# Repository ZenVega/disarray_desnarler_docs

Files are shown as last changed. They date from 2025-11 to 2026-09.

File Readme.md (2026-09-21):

# Macropad Collection

Open-hardware build documentation — KiCad projects, gerbers, bills of materials, laser-cut cases and artwork — for two custom macropads.

## The macropads

### [DisArray Desnarler](./disarray_desnarler/) &nbsp;→&nbsp; `disarray_desnarler/`

The original Schreibtischordnungsdienst macropad: a XIAO-RP2040 pad with hot-swap switches, an analog fader, and an optional rotary encoder, flashed with QMK. Includes the full build guide, laser-cut case, 3D-printed fader knob, sticker artwork, and the configuration instructions.

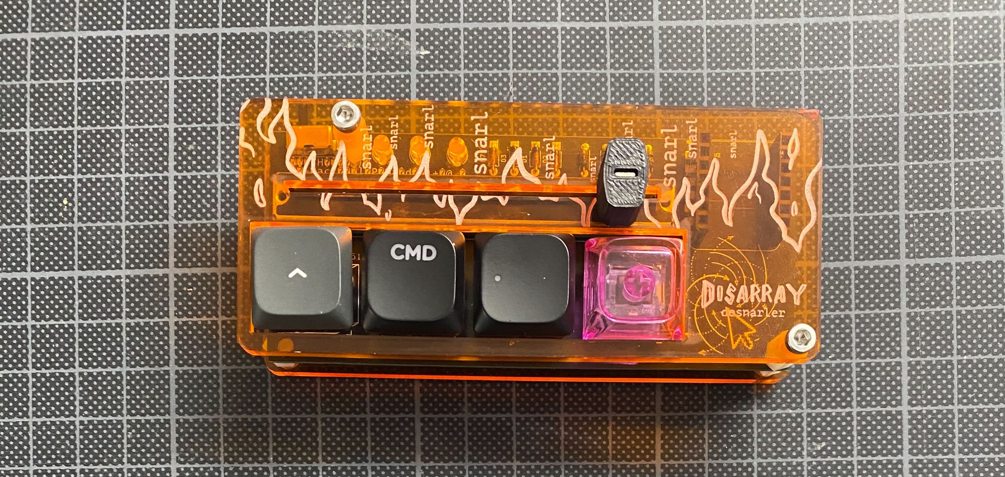
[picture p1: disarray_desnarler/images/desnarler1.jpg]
DisArray Desnarler


For a project overview, see [the Hackaday project page](https://hackaday.io/project/204536-disarray-desnarler).

### [macro_GOAT](./macro_GOAT/) &nbsp;→&nbsp; `macro_GOAT/`

An RP2040-Zero macropad with a 16-LED WS2812B array, hot-swap switches, and up to 4 optional EC11 rotary encoders. Includes the KiCad project, gerbers, SMD stencil, and the board artwork.

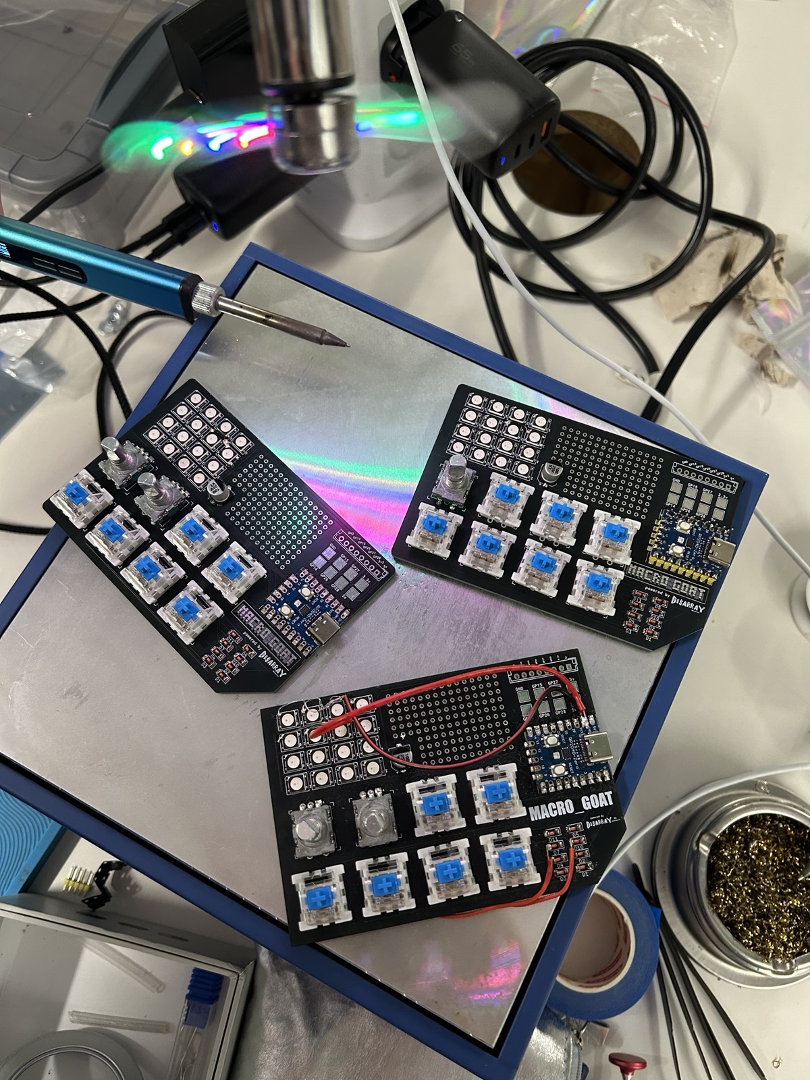
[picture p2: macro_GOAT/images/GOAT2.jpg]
macro_GOAT


Both pads share the QMK firmware repository [ZenVega/qmk_disarray_desnarler](https://github.com/ZenVega/qmk_disarray_desnarler), which now holds keymaps for the Desnarler and the macro_GOAT.

## Repository layout

```
disarray_desnarler/      first macropad (build docs, PCB versions, case, configuration instructions)
macro_GOAT/              second macropad (PCB, gerbers, stencil, artwork)
instructions/            shared QMK flashing guide used by both boards
symbols_and_footprints/  shared KiCad symbol & footprint libraries used by both boards
```

> **KiCad note:** each project's `fp-lib-table` / `sym-lib-table` still contains machine-specific
> paths from the original authoring environment. The shared libraries now live at the repo root in
> [`symbols_and_footprints/`](./symbols_and_footprints/); re-point the library tables there when
> opening a project in KiCad.

## License

See [LICENSE](./LICENSE).

&mdash; _your Schreibtischordnungsdienst_

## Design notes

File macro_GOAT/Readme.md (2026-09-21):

# macro_GOAT

A custom macropad built around an RP2040-Zero with a 16-LED WS2812B array, hot-swap
switches, and up to 4 optional EC11 rotary encoder.

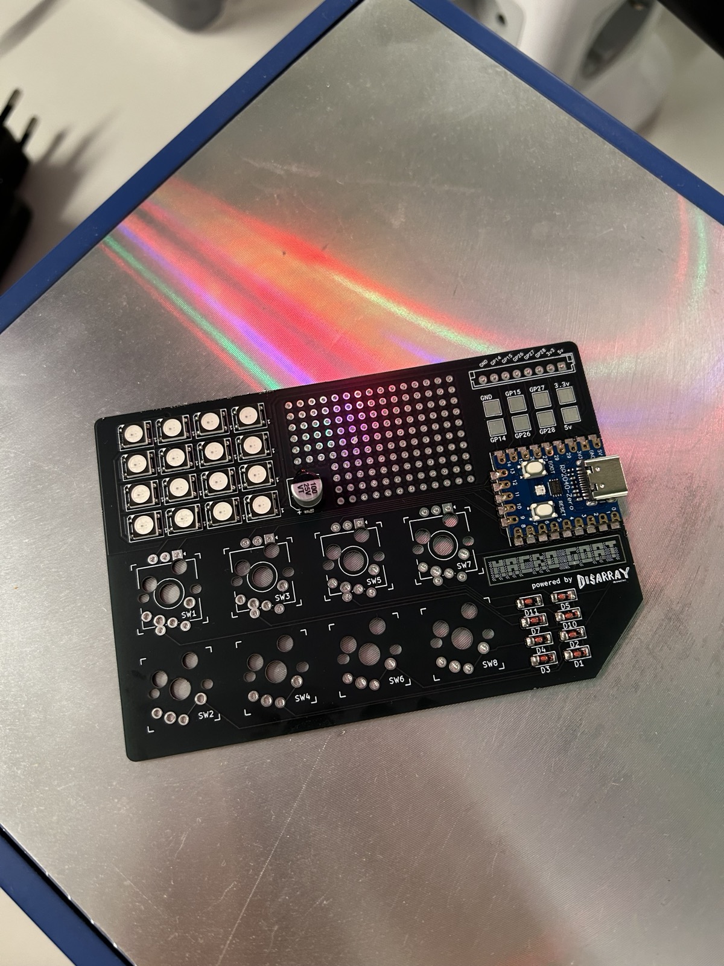
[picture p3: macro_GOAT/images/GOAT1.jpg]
macro_GOAT

macro_GOAT

🎬 [Watch the demo video](./images/GOAT_demo.mp4)

## What's in this folder

```
pcb/v1.0/        KiCad project, gerbers, SMD stencil and BOM.md
  gerbers/         fabrication gerbers (+ stencil/ for the SMD stencil)
  chaos_array.*    KiCad schematic / board / project files
  smd_stencil.svg  stencil artwork
  BOM.md           bill of materials
artwork/         board graphics — the macro_GOAT logo studies and silkscreen text
images/          build photos and demo video
```

> The KiCad project files are still named `chaos_array.*` (the board's original name).
> The shared KiCad symbol and footprint libraries live at the repository root in
> [`../symbols_and_footprints/`](../symbols_and_footprints/); the project's
> `fp-lib-table` / `sym-lib-table` may need re-pointing there when opening in KiCad.

## Bill of materials

See [`pcb/v1.0/BOM.md`](./pcb/v1.0/BOM.md).

## Firmware

The macro_GOAT keymap lives in the shared QMK repository
[ZenVega/qmk_disarray_desnarler](https://github.com/ZenVega/qmk_disarray_desnarler)
(alongside the DisArray Desnarler keymap). Flash it with QMK using the shared
[flashing guide](../instructions/How_to_flash.md).

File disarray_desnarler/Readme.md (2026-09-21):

# DisArray Desnarler

Congrats on getting your first own DisArray Desnarler. We are happy to have you here and help you organise your desktop.

For a quick overview of the project, have a look at [the Hackaday project page](https://hackaday.io/project/204536-disarray-desnarler).

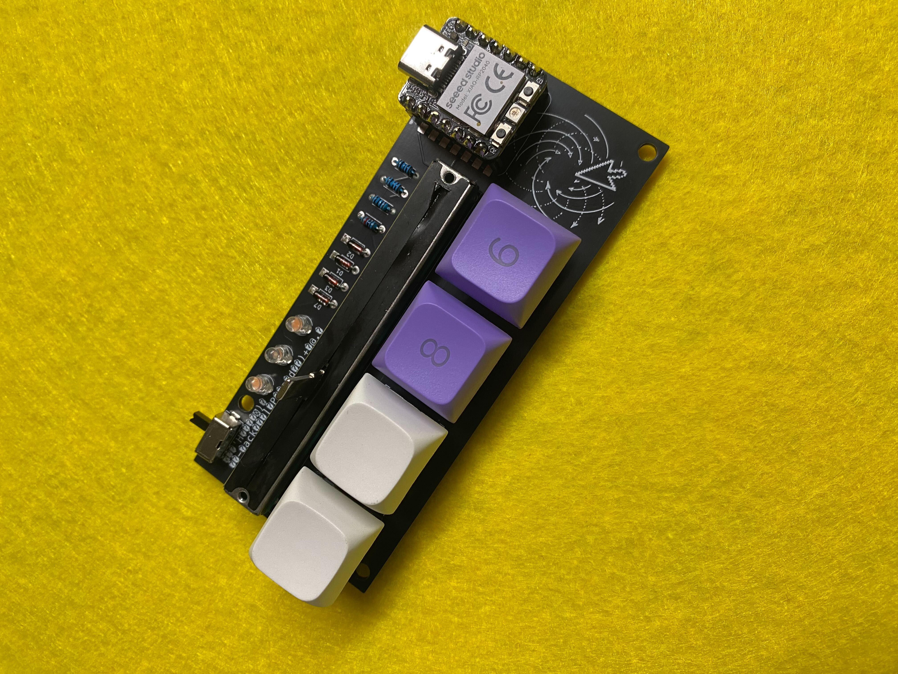
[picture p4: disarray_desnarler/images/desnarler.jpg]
DisArray Desnarler


&mdash; _your Schreibtischordnungsdienst_

## What's in this folder

```
pcb/v1.1/        current PCB — KiCad project, gerbers and BOM.md
pcb/v0.5/        earlier PCB revision (archived)
instructions/    configuration and Umlaut guides (flashing guide is shared, see ../instructions/)
case/            laser-cut case (current_version/ + old_version/)
build_guide/     assembly build diagram
3d_prints/       fader knob STL
logo/            logo and sticker artwork
images/          photos and diagrams
artwork/         PCB silkscreen / mask vector art
```

The shared KiCad symbol and footprint libraries live at the repository root in [`../symbols_and_footprints/`](../symbols_and_footprints/).

## Soldering instructions

The PCBs are sponsored by [PCBWay](https://www.pcbway.com/). Thanks for the support. Check out their services for high-quality PCBs and fast service.

All components should be soldered to the front of the board, with the exception of the optional hotswap sockets (d).

The alphabetical markers in this diagram show the recommended soldering order, based on the height of the components. Note that while "a" through "c" are next to each other in the diagram, the rest of the sequence is scattered. Be careful not to simply go clockwise.

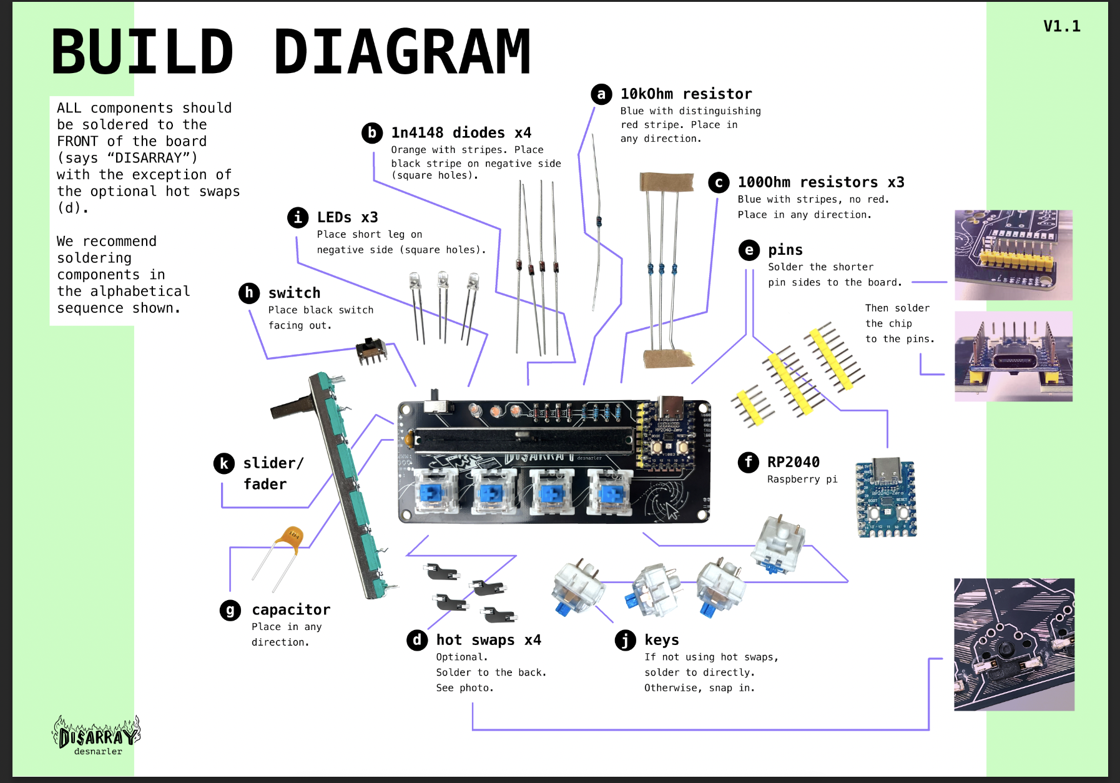
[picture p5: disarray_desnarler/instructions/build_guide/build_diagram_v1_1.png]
Soldering instructions


The full bill of materials is in [`pcb/v1.1/BOM.md`](./pcb/v1.1/BOM.md).

### Using the Desnarler as a Macropad

After you are done soldering, it is time to flash your Desnarler with some QMK firmware to make it ready for use. Let's start with a keymap we provide.

For this, please refer to the [How_to_flash](../instructions/How_to_flash.md) guide.

If you are interested in configuring the Desnarler yourself, see [How_to_configure](./instructions/How_to_configure.md).

If you are looking for an option to change the meaning of the keys a bit more easily check out the [Companion App](https://github.com/ZenVega/qmk_disarray_desnarler/blob/main/companion-app/README.md) (works with MacOS only).

### What you can also do

You can also use your Desnarler to play [Vimchaser!](https://github.com/uschi909/vimchaser)

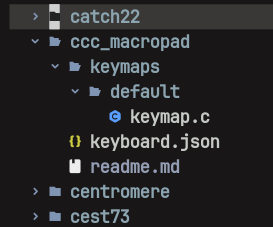
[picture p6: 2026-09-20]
disarray_desnarler/images/qmk_keyboard_files.png

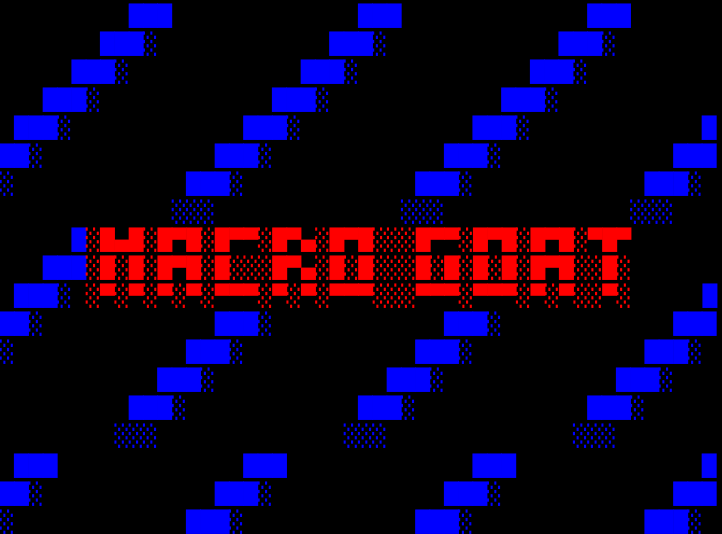
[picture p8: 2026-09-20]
macro_GOAT/artwork/ascii-art-text.png

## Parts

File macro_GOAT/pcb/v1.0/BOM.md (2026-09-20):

#Bill of Materials

| part | amount | link |
| --- | --- | --- |
| WS2812B RGB LED | 16 | https://de.aliexpress.com/item/4001345875756.html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 |
| LLIN4148 | 8 | https://de.aliexpress.com/item/1005006783983904.html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 |
| EC11 Rotary Encoder | optional | https://de.aliexpress.com/item/1005010636860645.html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 |

:

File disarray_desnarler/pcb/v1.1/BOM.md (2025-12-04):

| Reference | Qty | Value | Price / Amount | Datasheet 
| :--- | ---:| :--- | --- | :---
| D1, D2, D3,D7 |  4  | 1N4148WT | 1.09 / 100 | [Link](https://de.aliexpress.com/item/1005007807649334.html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) 
| D6, D8, D9 |  3  | LED | 2.19 / 100 | [Pink version](https://de.aliexpress.com/item/1005003320296052.html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)
| R1, R2, R3 |  3  | 100R | 1.65 / 100 | [Link] (https://de.aliexpress.com/item/32847096736.html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)
| R4 |  1  | 10k | 0.99 / 100 | [Link] (https://de.aliexpress.com/item/1005008175194639.html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)
| RV1 |  1  | Analogue_input_slider 10k | 2.55 / 5 | [Link] (https://de.aliexpress.com/item/1005006306313902.html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)
| SW1,SW2,SW4,SW5 | 4 | SW_Push | | ~ 
| SW1,SW2,SW4,SW5 | 4 | kaihl_hot_swaps | 2.99 / 30 | [Link] (https://de.aliexpress.com/item/1005009443356291.html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)
SW3           |  1  | OS/Left_Right-hand_Switch      | 1.69 / 50      | [Link](https://de.aliexpress.com/item/1005006123805028.html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,scm-url:1007.40050.354490.0,pvid:71a908dc-51c8-4ef3-aafd-85a7bed5551c,tpp_buckets:668%232846%238107%231934&pdp_ext_f=%7B%22order%22%3A%2271%22%2C%22eval%22%3A%221%22%2C%22sceneId%22%3A%2230050%22%2C%22fromPage%22%3A%22recommend%22%7D&pdp_npi=6%40dis%21EUR%214.97%211.69%21%21%2140.60%2113.80%21%40211b618e17595754708595171e8e66%2112000035859852610%21rec%21DE%216126981087%21XZ%211%210%21n_tag%3A-29919%3Bd%3A46f825b0%3Bm03_new_user%3A-29895&utparam-url=scene%3ApcDetailTopMoreOtherSeller%7Cquery_from%3A%7Cx_object_id%3A1005006123805028%7C_p_origin_prod%3A)         
| U1            |  1  | XIAO-RP2040-DIP              |                | ~

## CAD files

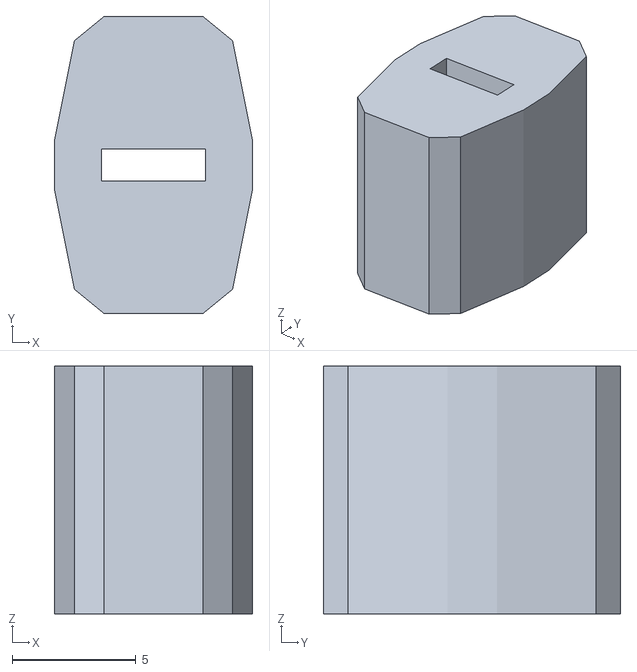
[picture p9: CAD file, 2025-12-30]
disarray_desnarler/3d_prints/Fader_knob-Body.stl
8.00 x 12.0 x 10.0

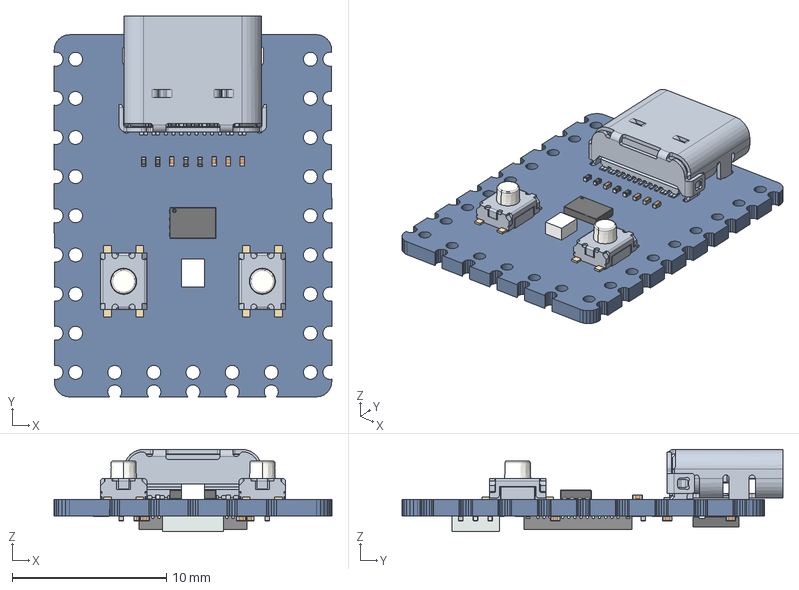
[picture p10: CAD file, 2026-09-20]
symbols_and_footprints/RP2040_Zero.stp
18.0 x 24.7 x 5.34 mm
BOARD
ANSCHL_X_FCSSE_1 x 9
K_X_F6RPER_1 x 9
EXTRUDED-32530
USER_LIBRARY-CHIP_CAP_MLCC_0201 x 19
EXTRUDED-36548
USER_LIBRARY-RP2040_QFN56_04
USER_LIBRARY-8MA3_1
USER_LIBRARY-8MA3_2
EXTRUDED-175432
EXTRUDED-175804 x 5
TS-1185EC-A-E-A-1 x 2
EXTRUDED-374538 x 10

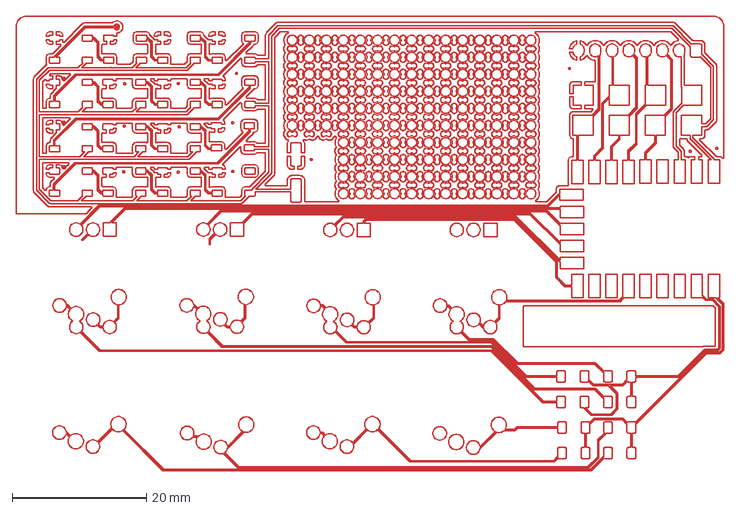
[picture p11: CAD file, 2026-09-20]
macro_GOAT/pcb/v1.0/gerbers/stencil/chaos_array-Front.dxf
105.4 x 67.7 mm

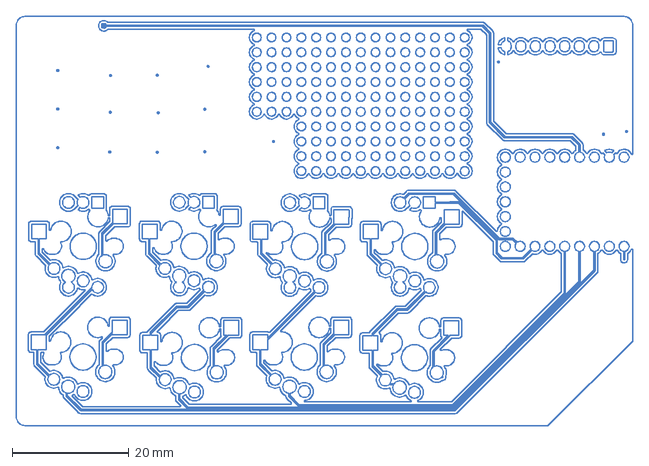
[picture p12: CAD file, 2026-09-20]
macro_GOAT/pcb/v1.0/gerbers/stencil/chaos_array-Back.dxf
105.4 x 70.0 mm

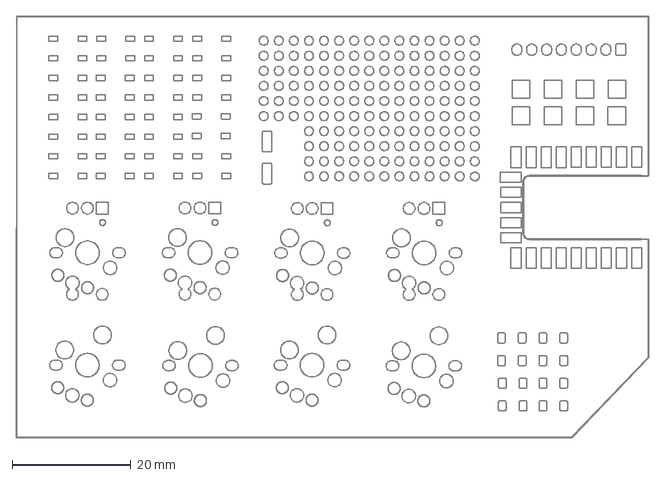
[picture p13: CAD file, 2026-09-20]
macro_GOAT/pcb/v1.0/gerbers/stencil/smd_stencil.dxf
106.5 x 71.0 mm

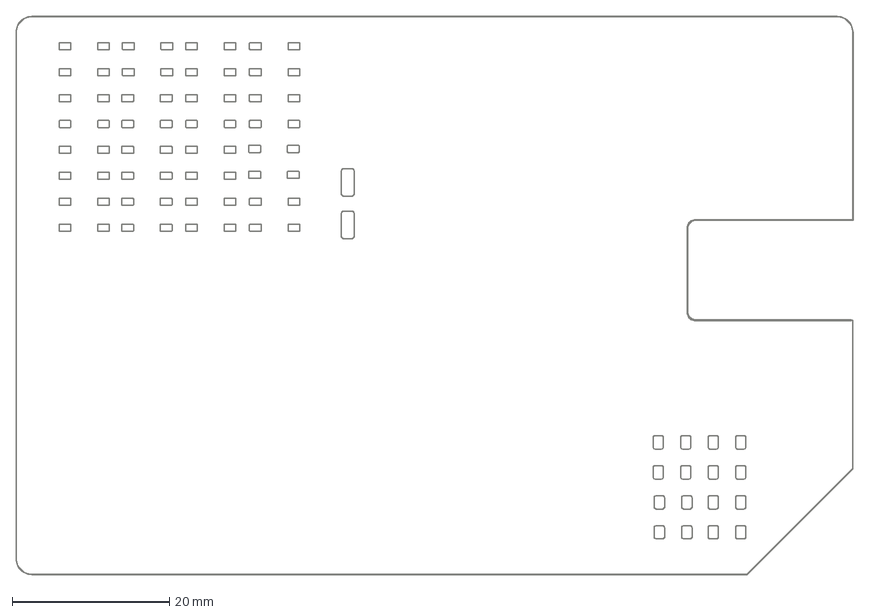
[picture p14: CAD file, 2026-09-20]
macro_GOAT/pcb/v1.0/gerbers/stencil/chaos_array-Edge_Cuts.dxf
106.5 x 71.0 mm

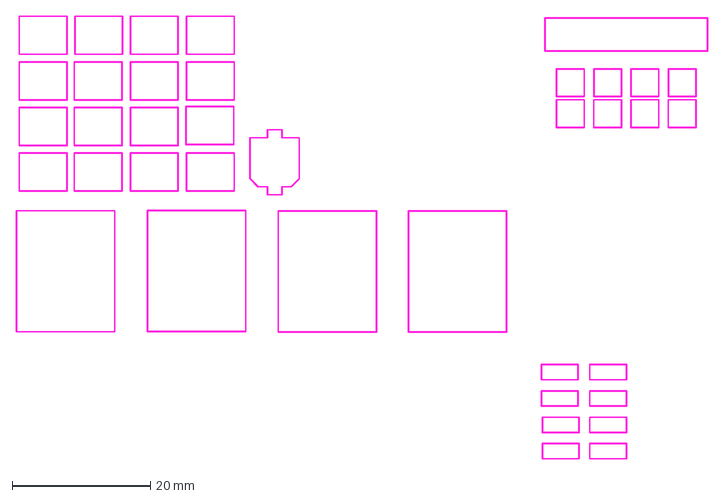
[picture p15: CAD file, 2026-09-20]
macro_GOAT/pcb/v1.0/gerbers/stencil/chaos_array-F_Courtyard.dxf
100.0 x 64.1 mm

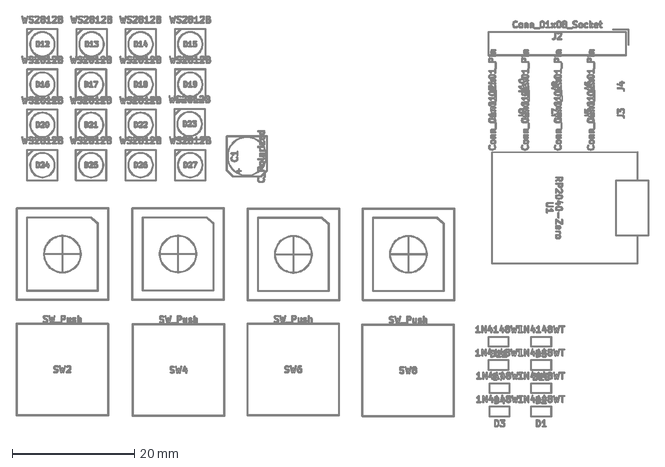
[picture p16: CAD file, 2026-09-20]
macro_GOAT/pcb/v1.0/gerbers/stencil/chaos_array-F_Fab.dxf
103.7 x 67.3 mm

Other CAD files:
macro_GOAT/pcb/v1.0/gerbers/stencil/chaos_array-B_Courtyard.dxf
macro_GOAT/pcb/v1.0/gerbers/stencil/chaos_array-Margin.dxf
macro_GOAT/pcb/v1.0/gerbers/stencil/chaos_array-B_Mask.dxf
macro_GOAT/pcb/v1.0/gerbers/stencil/chaos_array-B_Paste.dxf
macro_GOAT/pcb/v1.0/gerbers/stencil/chaos_array-B_Silkscreen.dxf
macro_GOAT/pcb/v1.0/gerbers/stencil/chaos_array-F_Mask.dxf
macro_GOAT/pcb/v1.0/gerbers/stencil/chaos_array-F_Paste.dxf
macro_GOAT/pcb/v1.0/gerbers/stencil/chaos_array-F_Silkscreen.dxf

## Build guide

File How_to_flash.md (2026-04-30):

### Great! you finished soldering!

### so let's go ahead and flash some firmware onto your Desnarler!

If you are in a workshop with us, we will help you and flash the first round with you, or you even got an already flashed microcontroller.

If you feel comfortable with the terminal and an IDE of your choice: This guide is for you.



# Prepare: Install QMK

This is just a quick recap. If you get stuck, check the official qmk documentation [here](https://docs.qmk.fm/newbs_getting_started)

In order to get QMK CLI installed on your system follow the first two steps from the [installation instructions] (https://docs.qmk.fm/newbs_getting_started)

Test if installation was successfull:

```bash
qmk --version
```

# Flash Desnarler

Clone this [repo](https://github.com/ZenVega/qmk_for_macropad/tree/main) containing the firmware and the macropad layout and keymap.

To install all missing dependencies run:

```bash
git submodule update --init --recursive

git submodule sync --recursive
git submodule update --init --recursive --force
```

## Chose Keymap

We provide a few different keymaps, that we think will be useful to you.
When you look around in the repo you just cloned, there is a directory "keyboards". Within this choose the directory corresponding to the keyboard you have - in your case it is a DesnarlerV1. Within this directory there are different keymaps to configure what your Desnarler does.

### default keymap

As the name says, this keymap should be used on a Linux OS.
There are two independent sets of layouts.

If the switch on the top left of the Desnarler is to the left:

- The 2 most right keys will navigate workspaces without dragging your current window.
- Pressing the left most key plus one of the right most keys will navigate through workspaces while dragging the current window along.
- Pressing the second key to the left will activate the 2 right keys to circle through all the open applications
- holding the 2 right most keys and pressing one of the other 2 will log you out or put your system to sleep

If the switch it to the right, the focus is on rearranging the windows within a workspace

- the 2 left most keys will move the currently active windows to the left or right half of the screen.
- having activated the left most key, the 2 keys on the right will maximize and minimize the current window
- holding the second key to the left will let you switch workspaces without dragging the current window
- holding the 2 right most keys and pressing one of the other 2 will log you out or put your system to sleep

More information on this map and an easy introduction into QMK you will find [here](./How_to_configure.md)

### German Umlaute ä, ö, ü

This keymap has the German Umlaute on the second set of layers (switch to the right), including the option to get the capital Umlaute. More thoughts on this map and a slightly deeper dive into QMK [here](./How_to_Umlaut.md)

## Compile

After you have chosen your preferred keymap, you are ready to compile.

Compilation will create a \*.bin that holds the firmware including your compilation ready to be flashed on the MCU

```bash
qmk compile -kb <keyboard> -km <keymap>
```

so a likely use will be

```bash
qmk compile -kb desnarler_v1 -km default
```

If no keyboard is defined, your keymap is 'default'. (which might not be defined in all cases)

### Flash

After compilation you are ready to flash qmk to your microcontroller (rp2040 in this case): plug it in and set it into bootloader mode.
This requires pressing the boot button while plugging it in. The device should show up as a flashable media in your files-explorer.
run:

```bash
qmk flash -kb <keyboard> -km <keymap>
```

so likely you will use

```bash
qmk flash -kb desnarler_v1 -km default
```

#### Troubleshooting Flashing

If your have done minor changes to your firmware, flashed and everything seemed fine, but the old firmware is still booting, download this [nuke file](https://datasheets.raspberrypi.com/soft/flash_nuke.uf2). Once downloaded, copy it onto your RP2040 while in bootloader mode. This will erase all traces of the former firmware. Then just flash again.

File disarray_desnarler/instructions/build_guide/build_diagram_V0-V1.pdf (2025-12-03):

V0-V1

# BUILD

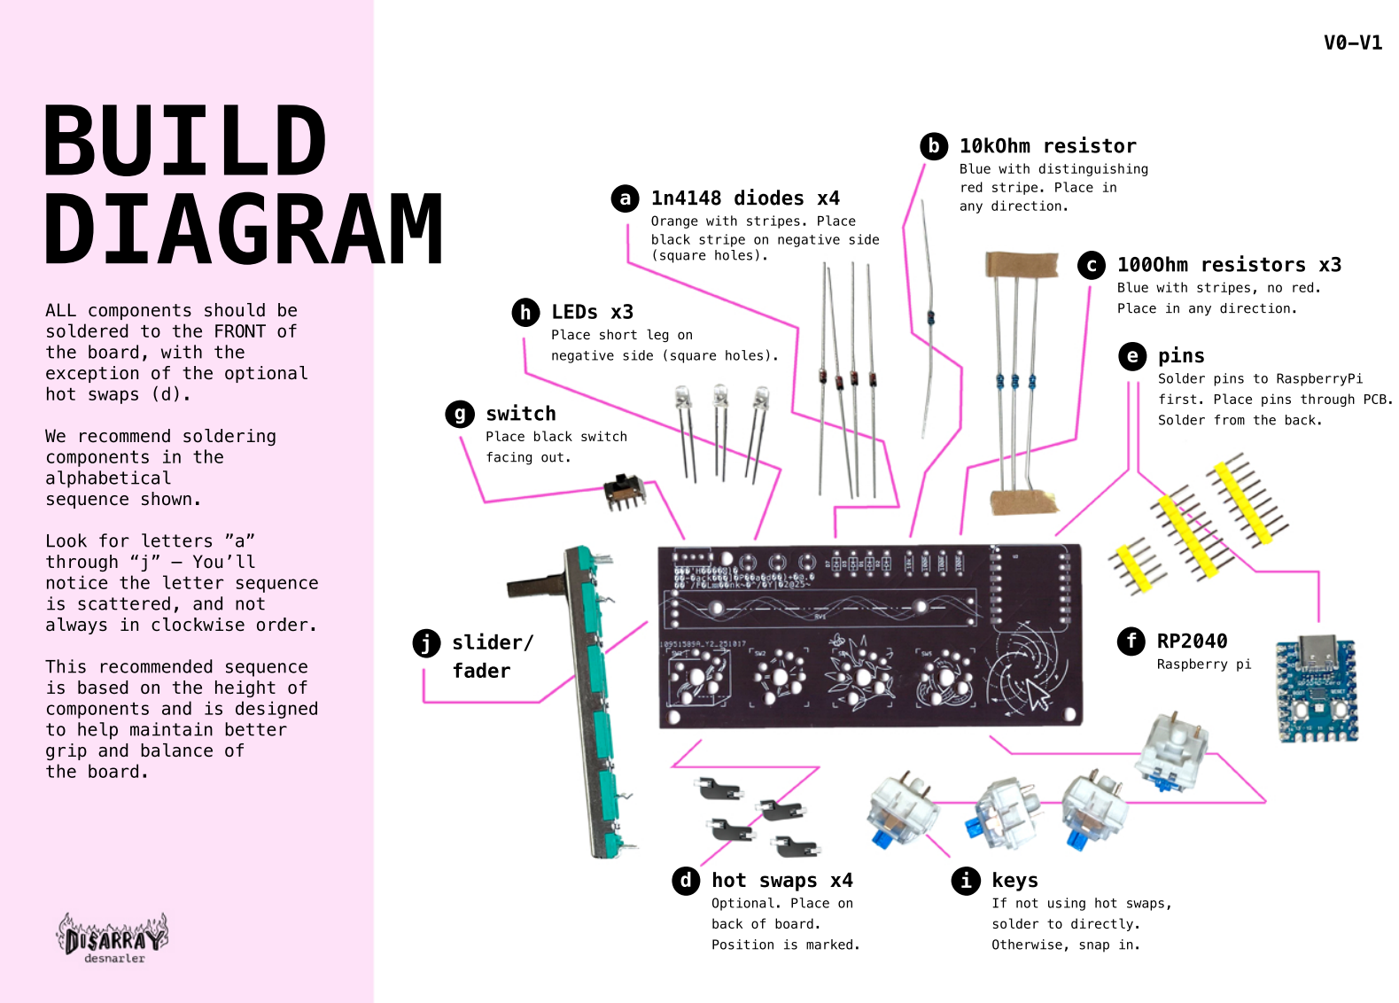
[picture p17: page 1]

## ALL components should be soldered to the FRONT of the board, with the exception of the optional

hot swaps (d).

## We recommend soldering components in the alphabetical

sequence shown.

## Look for letters ”a” through “j” — You’ll notice the letter sequence is scattered, and not

always in clockwise order.

## This recommended sequence is based on the height of components and is designed to help maintain better grip and balance of

the board.

## DIAGRAM a 1n4148 diodes x4

Orange with stripes. Place black stripe on negative side (square holes).

## b 10kOhm resistor

Blue with distinguishing
red stripe. Place in
any direction.

## c 100Ohm resistors x3

Blue with stripes, no red. Place in any direction.

## f RP2040

Raspberry pi

## e pins

Solder pins to RaspberryPi first. Place pins through PCB.
g switch | Solder from the back.
Place black switch
facing out.

## h LEDs x3

Place short leg on
negative side (square holes).

## j slider/ fader

## d hot swaps x4

Optional. Place on
back of board.
Position is marked.

## i keys

If not using hot swaps,
solder to directly.
Otherwise, snap in.

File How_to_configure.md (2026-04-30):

# How to configure the keymap yourself



To give you an easy introduction into how you can configure your Desnarler according to your needs, lets have a closer look into what is happening within the code of the keymaps. This will help you to figure out how to create a keymap yourself.

If you ever get stuck here, the reference will be the [official QMK documentation](https://docs.qmk.fm/newbs_getting_started)

If you feel comfortable with coding: this is just an easy intro for people less comfortable to change the Desnarler according to their needs. It might still be a good start for you as well, but of course you are free to look at the whole code to also get into the LEDs and the slider.

## A closer look into the keymaps

### an easy example

A big part of using QMK to customize any keyboard according to your needs is to be able to set the layout. This is happening within the keymap.c - file whhere you configure how your keyboard will behave.
In the [QMK documentation](https://docs.qmk.fm/) you will find big tables where you can figure out the names of all the keys you could potentially press [here](https://docs.qmk.fm/keycodes_basic).

Lets say you want to use just a single layout, where the keys are the keys A, B, 1, 2.
Then the layout would be
```bash
[0] = LAYOUT(KC_A, KC_B, KC_1, KC_2)
```
pretty easy to see why, isn't it?

### default_pure_linux
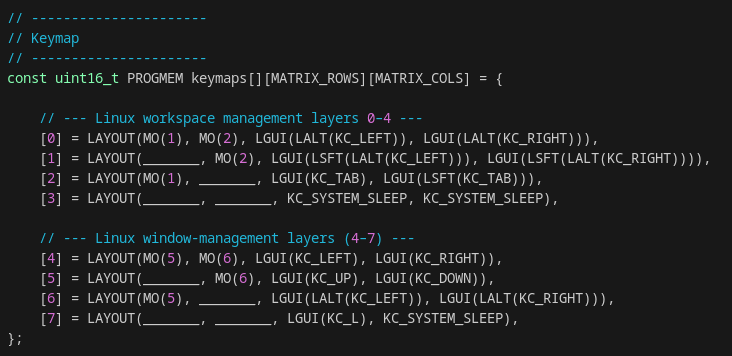
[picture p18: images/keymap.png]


Let us dive into the default keymap we provide and learn about the use of the modifier keys.

As you can see this code provides 8 different layouts to give the keys of your keyboard meaning.

The layouts are grouped into 2 groups, representing the whether the switch on the top left of the Desnarler is to the left (Layout 0-3) or to the right (Layouts 4-7). This is set up for you in another part of code - you don't need to worry about this.

For understanding it is important to realise that you will always fall back onto layout 0 or 4 respectively and this is also the default layout that is "on", when no key is pressed.

the 4 keys in layout 0:

- the first key MO(1) will change the layout to Layout 1 while held, just as MO(2) on the second key will change to Layout 2
- the third key will send the keys left GUI (also called Super or OS key), left Alt and the left arrow key at the same time
- just like the fourth key will send the keys left GUI - left Alt and the right arrow key at the same time

What you see in this example is how you can send multiple keys at the same time, if some of them are modifier keys. In easy words a modifier key is a key on your normal keyboard that changes the layout of your keyboard, when pressed. For instance to reach the layout that contains all the capital letters you hold the Shift key. So KC_A will write 'a' while LSFT(KC_A) will write 'A'. A list of the names of the Modifier Keys and the way to use them within QMK is [here](https://docs.qmk.fm/feature_advanced_keycodes).

Within the layouts of the default map, Desnarler acts as if the keys "pressed at the same time". For an example, where a keypress of the Desnarler leads to a series of keypress signals being send, habe a look in [How_to_Umlaut.md](./How_to_Umlaut.md.md).

We hope this helps as an introduction on how to configure your Desnarler just the way you need it. 

## Done creating your own keymap?
Then go ahead and flash it onto the Desnarler as described [here](./How_to_flash.md)

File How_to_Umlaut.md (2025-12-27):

# The Umlaut map – using a bit more complex features of qmk

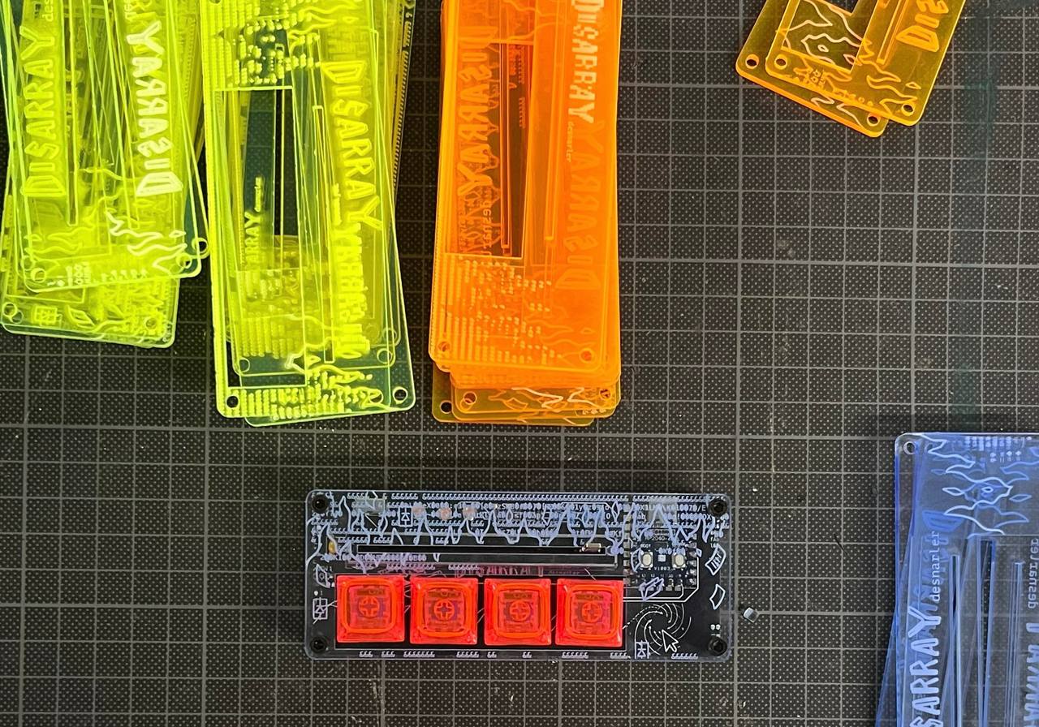
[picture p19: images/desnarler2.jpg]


### general idea and neccesary settings
If you want to type the German Umlaute Ä, Ö and Ü on a regular QWERTY keyboard, you will have to use [compose keys](https://en.wikipedia.org/wiki/Compose_key).
To get to ä you would use 
1) Compose 
2) Shift and “  
3) a

For this to work you need to locally set your custom compose key. An option that is regularly used is to have Compose on the right Alt. So this option will also be used within the Umlaut map. To set this you have to define the Compose key within the keyboard settings.

### peak into the code
After having set this, lets look at the code to procude an ä with our tiny Desnarler. We create an enum of Macros for all the Umlaute, we want to be able to use. 

These Macros are then called as keys within layout 4, while Layouts 0-3 remain as we know them from the default keymap.

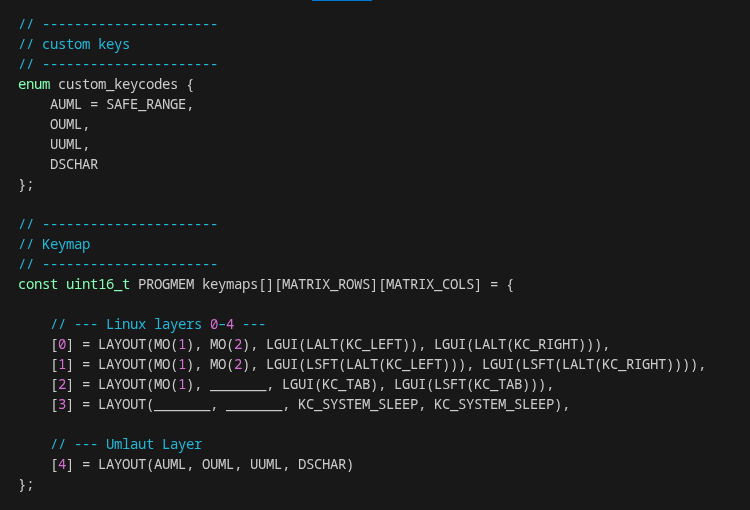
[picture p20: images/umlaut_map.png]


Because we are not calling a specific key or a simultaneous press of keys at the same time, we need to do things different than we did in layouts 0-3. This time we need to imitate pressing specific keys in a certain order.
For our purposes we use a function, that QMK offers:

```
bool process_record_user(uint16_t keycode, keyrecord_t *record) 
```
This function is called everytime a key is pressed or released and therefore is just the right spot for us to handle our custom Umlaut keys.

Let's look at AUML as an example:
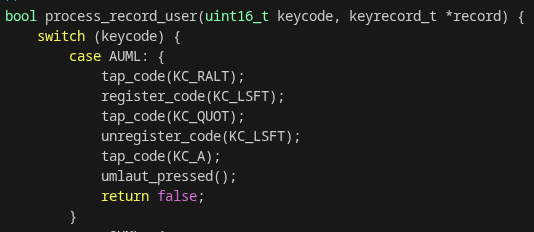
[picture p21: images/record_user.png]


In case we pressed the key that we labeld AUML in the Layout it's case will be called within this switch statement. Then we will tap (imitating one short keypress) our compose key, which is set to right Alt. Then we need to hold left shift while pressing [ " ]. So we register left shift and tap [ " ] before we unregister (let go of) left shift. This sequence is the same for all Umlaute. As we want Ä in this example, we tap KC_A and we are done. (the umlaut_pressed() function handles the LEDs on key press here).

You can learn more about several functions offered by QMK [here](https://docs.qmk.fm/custom_quantum_functions). There are functions once called at boot for instance or that are called in an endless loop. All to help you customise your keyboard.

### other ideas and lessons learned 
Ideas we had, or you potentially have: Is there an easier / less long approach to this? 
- QMK does not support Unicode. So sending the Unicode of the Umlaute is not possible. Only ascii characters are accepted
- it is possible to send strings (using send_string(char *str)). But well, ascii strings.
- there are language specific headers! won't they support sending unusual character? - nope, they just provide provides language-specific keycode aliases - this would only be useful if your normal keyboard is not set to be read as US ANSI but for instance German - but then there would also be no need for a seperate keyboard option to produce 'Ä'

#### options for the Umlaut map
- the current Umlaut map does not support capital Umlaute. The code for this is there!. But there are just 4 keys. So if you want to have ß, we are lacking a key for Capitalisation - but if you just choose to include the CCAP key you can have capital Ä, Ö, Ü (have a look into the real code of the keymap - what you have seen here is a shortened version :) )
- is there not an option to double use one physical key? there is! it would be using 
```
LT(layer selected on hold, key pressed on tap)
```
but: this does not work for "invented" keys as our AUML.

### Contribute!
This for now and for our current investigation results.

If you have more ideas for useful keymaps or want to share and show us how you are using your Desnarler: create a pull request 

loads of love - the DesktopOrdnungsamt

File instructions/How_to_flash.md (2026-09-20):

### Great! your macropad is built!

### so let's go ahead and flash some firmware onto it!

This guide applies to both the DisArray Desnarler and the macro_GOAT - they share the same QMK firmware repository and flashing process.

If you are in a workshop with us, we will help you and flash the first round with you, or you even got an already flashed microcontroller.

If you feel comfortable with the terminal and an IDE of your choice: This guide is for you.

# Prepare: Install QMK

This is just a quick recap. If you get stuck, check the official qmk documentation [here](https://docs.qmk.fm/newbs_getting_started)

In order to get QMK CLI installed on your system follow the first two steps from the [installation instructions] (https://docs.qmk.fm/newbs_getting_started)

Test if installation was successfull:

```bash
qmk --version
```

# Flash your macropad

Clone this [repo](https://github.com/ZenVega/qmk_disarray_desnarler) containing the firmware and the keymaps for both macropads.

To install all missing dependencies run:

```bash
git submodule update --init --recursive

git submodule sync --recursive
git submodule update --init --recursive --force
```

## Chose Keymap

We provide a few different keymaps, that we think will be useful to you.
When you look around in the repo you just cloned, there is a directory "keyboards". Within this choose the directory corresponding to the keyboard you have - `desnarler_v1` for the DisArray Desnarler, or `macro_goat_v0` for the macro_GOAT. Within this directory there are different keymaps to configure what your macropad does.

For a description of the keymaps we provide for the Desnarler and an easy introduction into QMK, see the Desnarler's [How_to_configure](../disarray_desnarler/instructions/How_to_configure.md) guide.

## Compile

After you have chosen your preferred keymap, you are ready to compile.

Compilation will create a \*.bin that holds the firmware including your compilation ready to be flashed on the MCU

```bash
qmk compile -kb <keyboard> -km <keymap>
```

so a likely use will be

```bash
qmk compile -kb desnarler_v1 -km default
```

or, for the macro_GOAT

```bash
qmk compile -kb macro_goat_v0 -km default
```

If no keyboard is defined, your keymap is 'default'. (which might not be defined in all cases)

### Flash

After compilation you are ready to flash qmk to your microcontroller (rp2040 in this case): plug it in and set it into bootloader mode.
This requires pressing the boot button while plugging it in. The device should show up as a flashable media in your files-explorer.
run:

```bash
qmk flash -kb <keyboard> -km <keymap>
```

so likely you will use

```bash
qmk flash -kb desnarler_v1 -km default
```

#### Troubleshooting Flashing

If your have done minor changes to your firmware, flashed and everything seemed fine, but the old firmware is still booting, download this [nuke file](https://datasheets.raspberrypi.com/soft/flash_nuke.uf2). Once downloaded, copy it onto your RP2040 while in bootloader mode. This will erase all traces of the former firmware. Then just flash again.

If the changes you made to your config don't act as intended, nuke the MCU: put it into bootloader mode, then drag and drop this [nuke file](./files/universal_flash_nuke.uf2) onto the newly mounted storage device. Then just flash again.

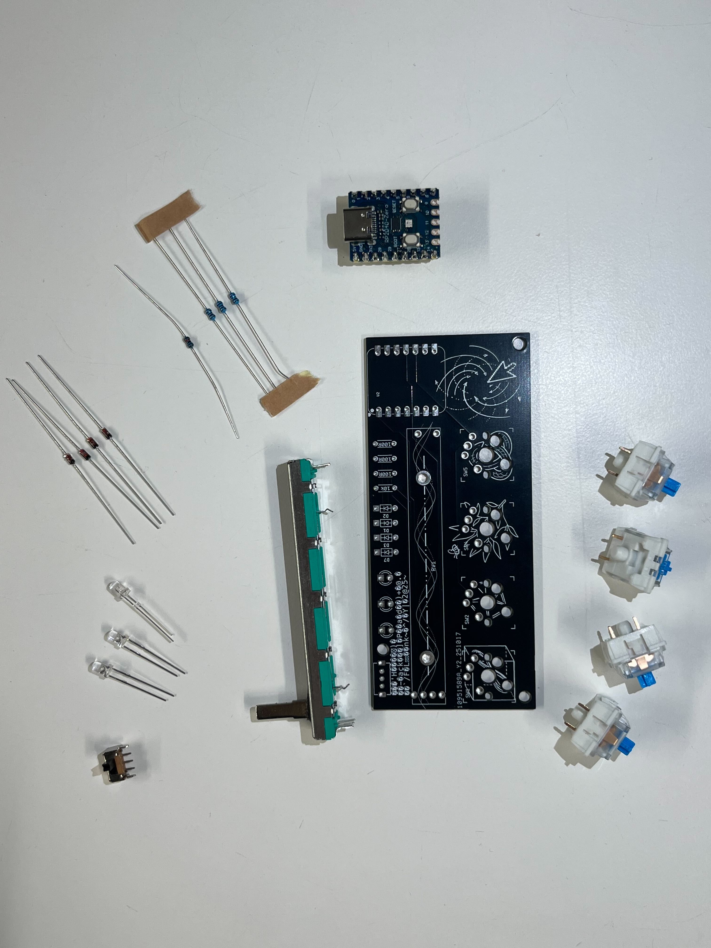
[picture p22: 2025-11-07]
build_guide/images/IMG_5155.jpg

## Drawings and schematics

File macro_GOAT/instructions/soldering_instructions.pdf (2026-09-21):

# BUILD DIAGRAM

## WS2812B (rgb LED)

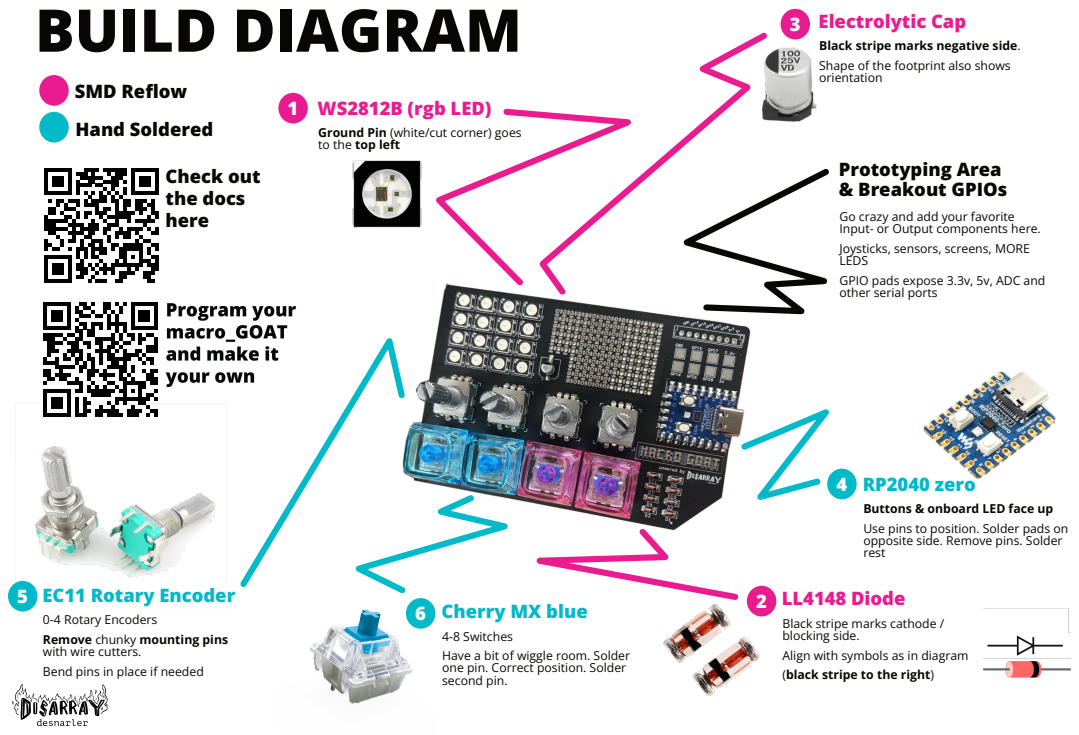
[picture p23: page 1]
Prototyping Area & Breakout GPIOs; SMD Reflow; Check out the docs here; Hand Soldered

Electrolytic Cap
Black stripe marks negative side.
Shape of the footprint also shows
orientation

Ground Pin (white/cut corner) goes
to the top left

Go crazy and add your favorite
Input- or Output components here.
Joysticks, sensors, screens, MORE
LEDS
GPIO pads expose 3.3v, 5v, ADC and
other serial ports

RP2040 zero
Buttons & onboard LED face up
Use pins to position. Solder pads on
opposite side. Remove pins. Solder
rest

EC11 Rotary Encoder
0-4 Rotary Encoders
Remove chunky mounting pins
with wire cutters.
Bend pins in place if needed

LL4148 Diode
Black stripe marks cathode /
blocking side.
Align with symbols as in diagram
(black stripe to the right)

Cherry MX blue
4-8 Switches
Have a bit of wiggle room. Solder
one pin. Correct position. Solder
second pin.

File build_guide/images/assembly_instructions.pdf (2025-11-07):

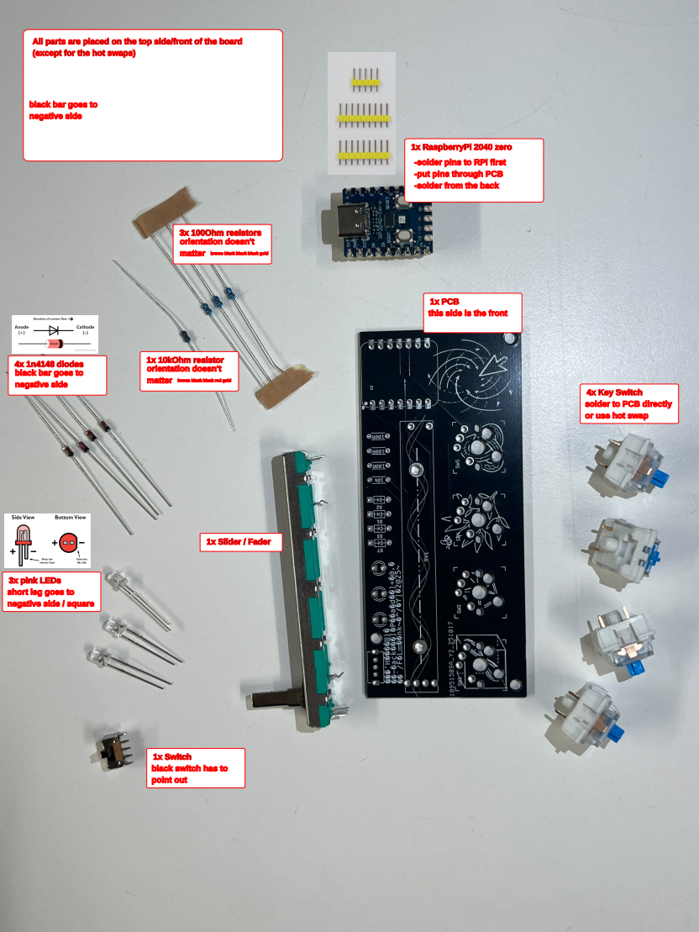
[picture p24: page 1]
1x 10kOhm resistor orientation doesn't; 3x 100Ohm resistors orientation doesn't matter; 1x Slider / Fader

All parts are placed on the top side/front of the board
(except for the hot swaps)

black bar goes to
negative side

1x RaspberryPi 2040 zero
-solder pins to RPi first
-put pins through PCB
-solder from the back

brown black black black gold

1x PCB
this side is the front

4x 1n4148 diodes

matter brown black black red gold

4x Key Switch
solder to PCB directly
or use hot swap

3x pink LEDs
short leg goes to
negative side / square

1x Switch
black switch has to
point out

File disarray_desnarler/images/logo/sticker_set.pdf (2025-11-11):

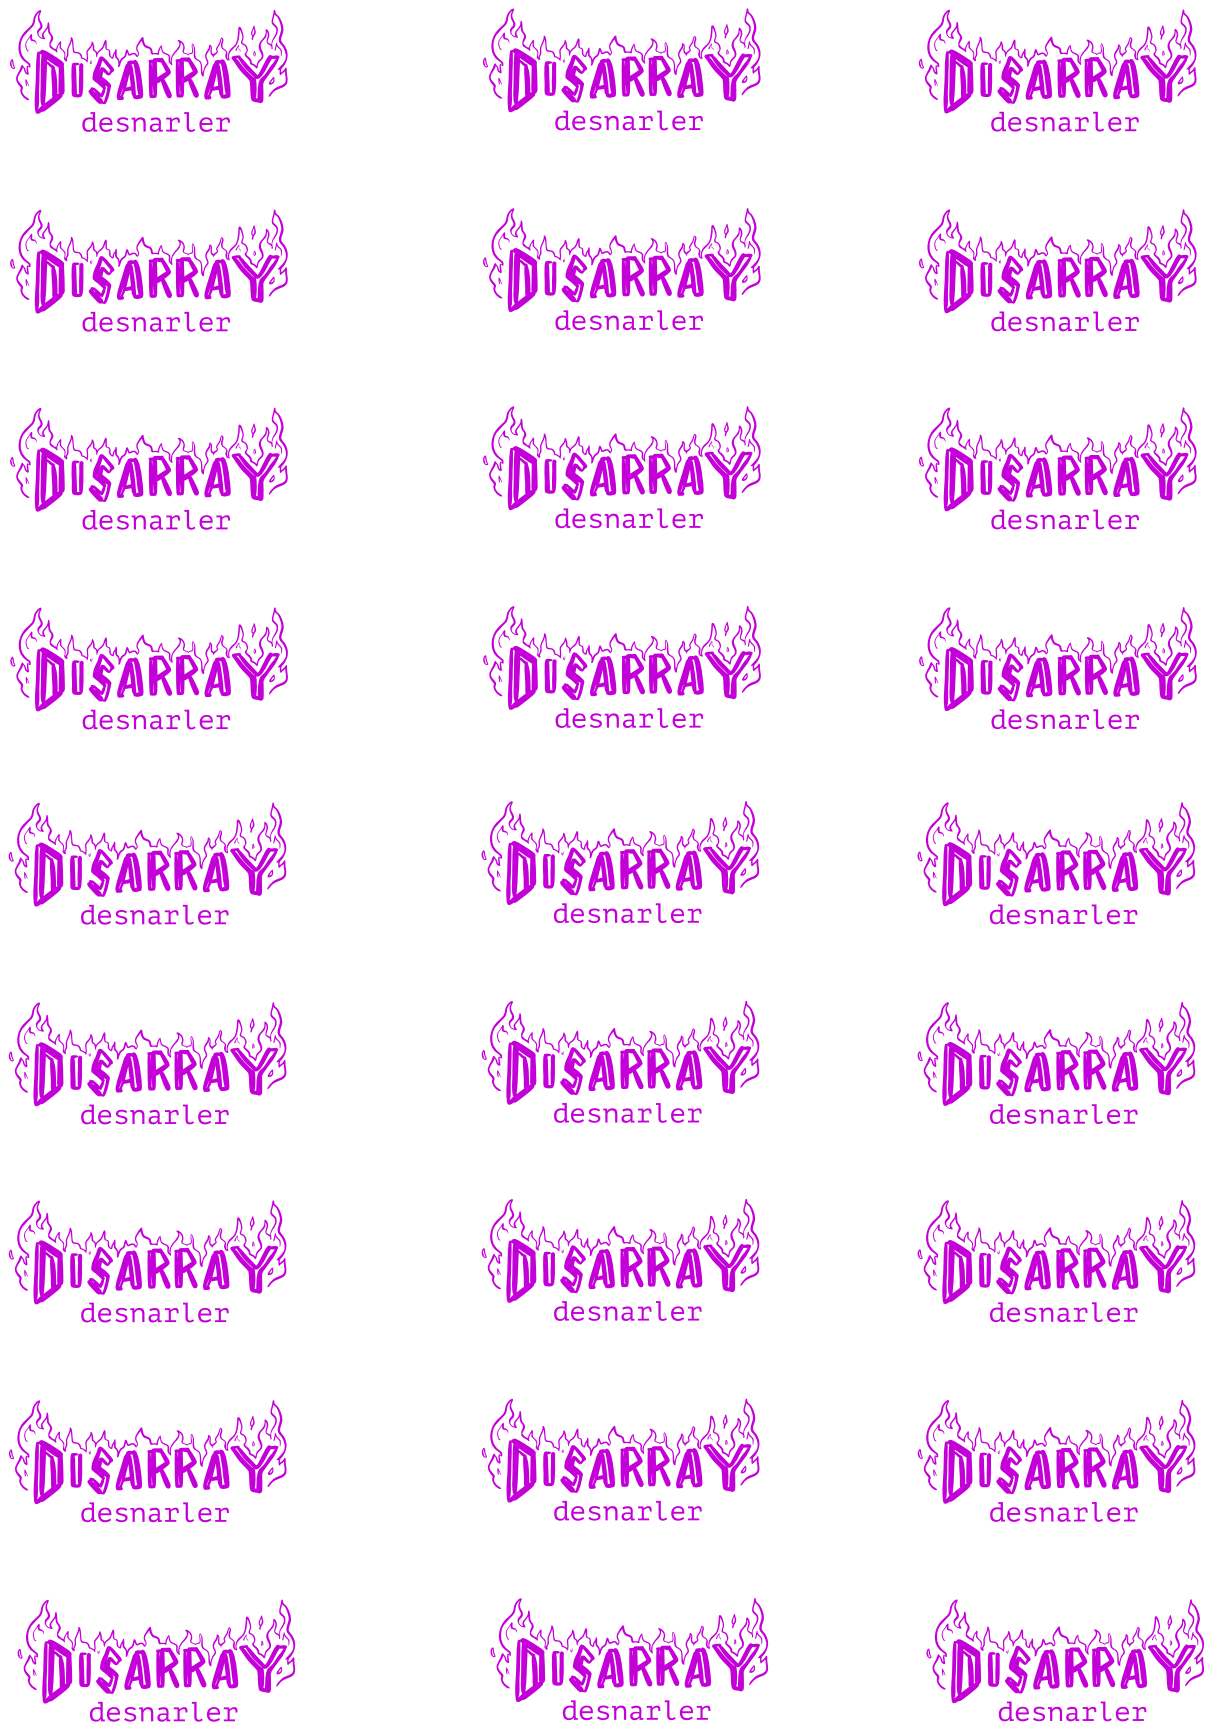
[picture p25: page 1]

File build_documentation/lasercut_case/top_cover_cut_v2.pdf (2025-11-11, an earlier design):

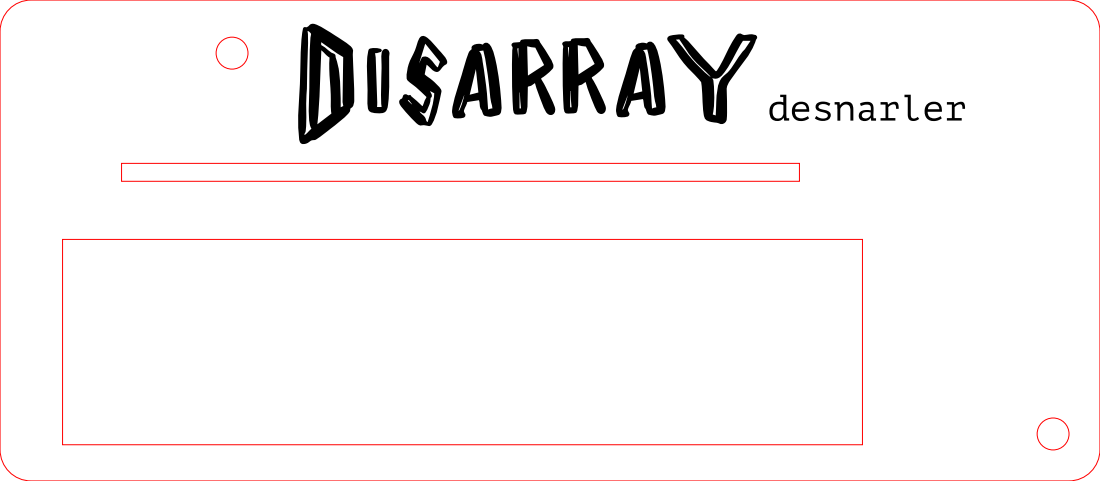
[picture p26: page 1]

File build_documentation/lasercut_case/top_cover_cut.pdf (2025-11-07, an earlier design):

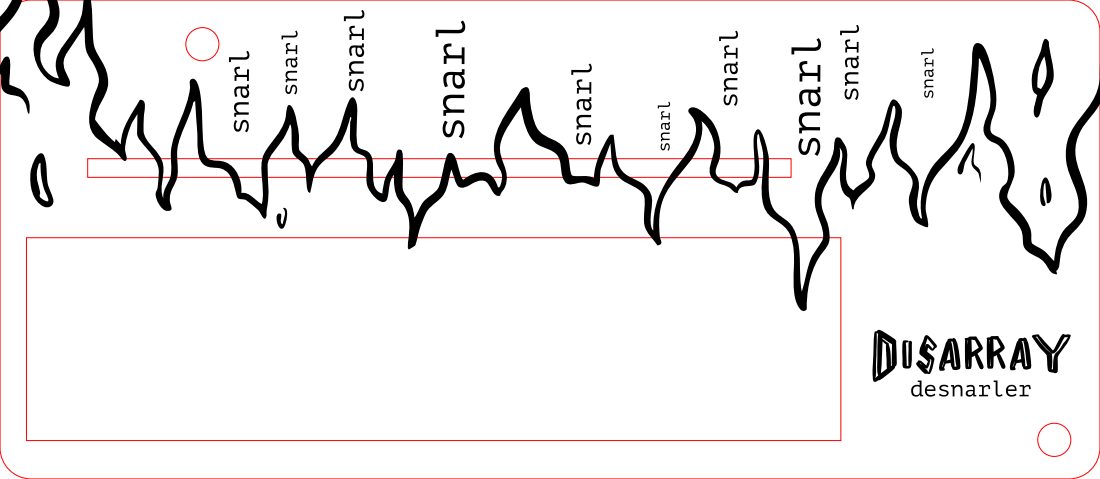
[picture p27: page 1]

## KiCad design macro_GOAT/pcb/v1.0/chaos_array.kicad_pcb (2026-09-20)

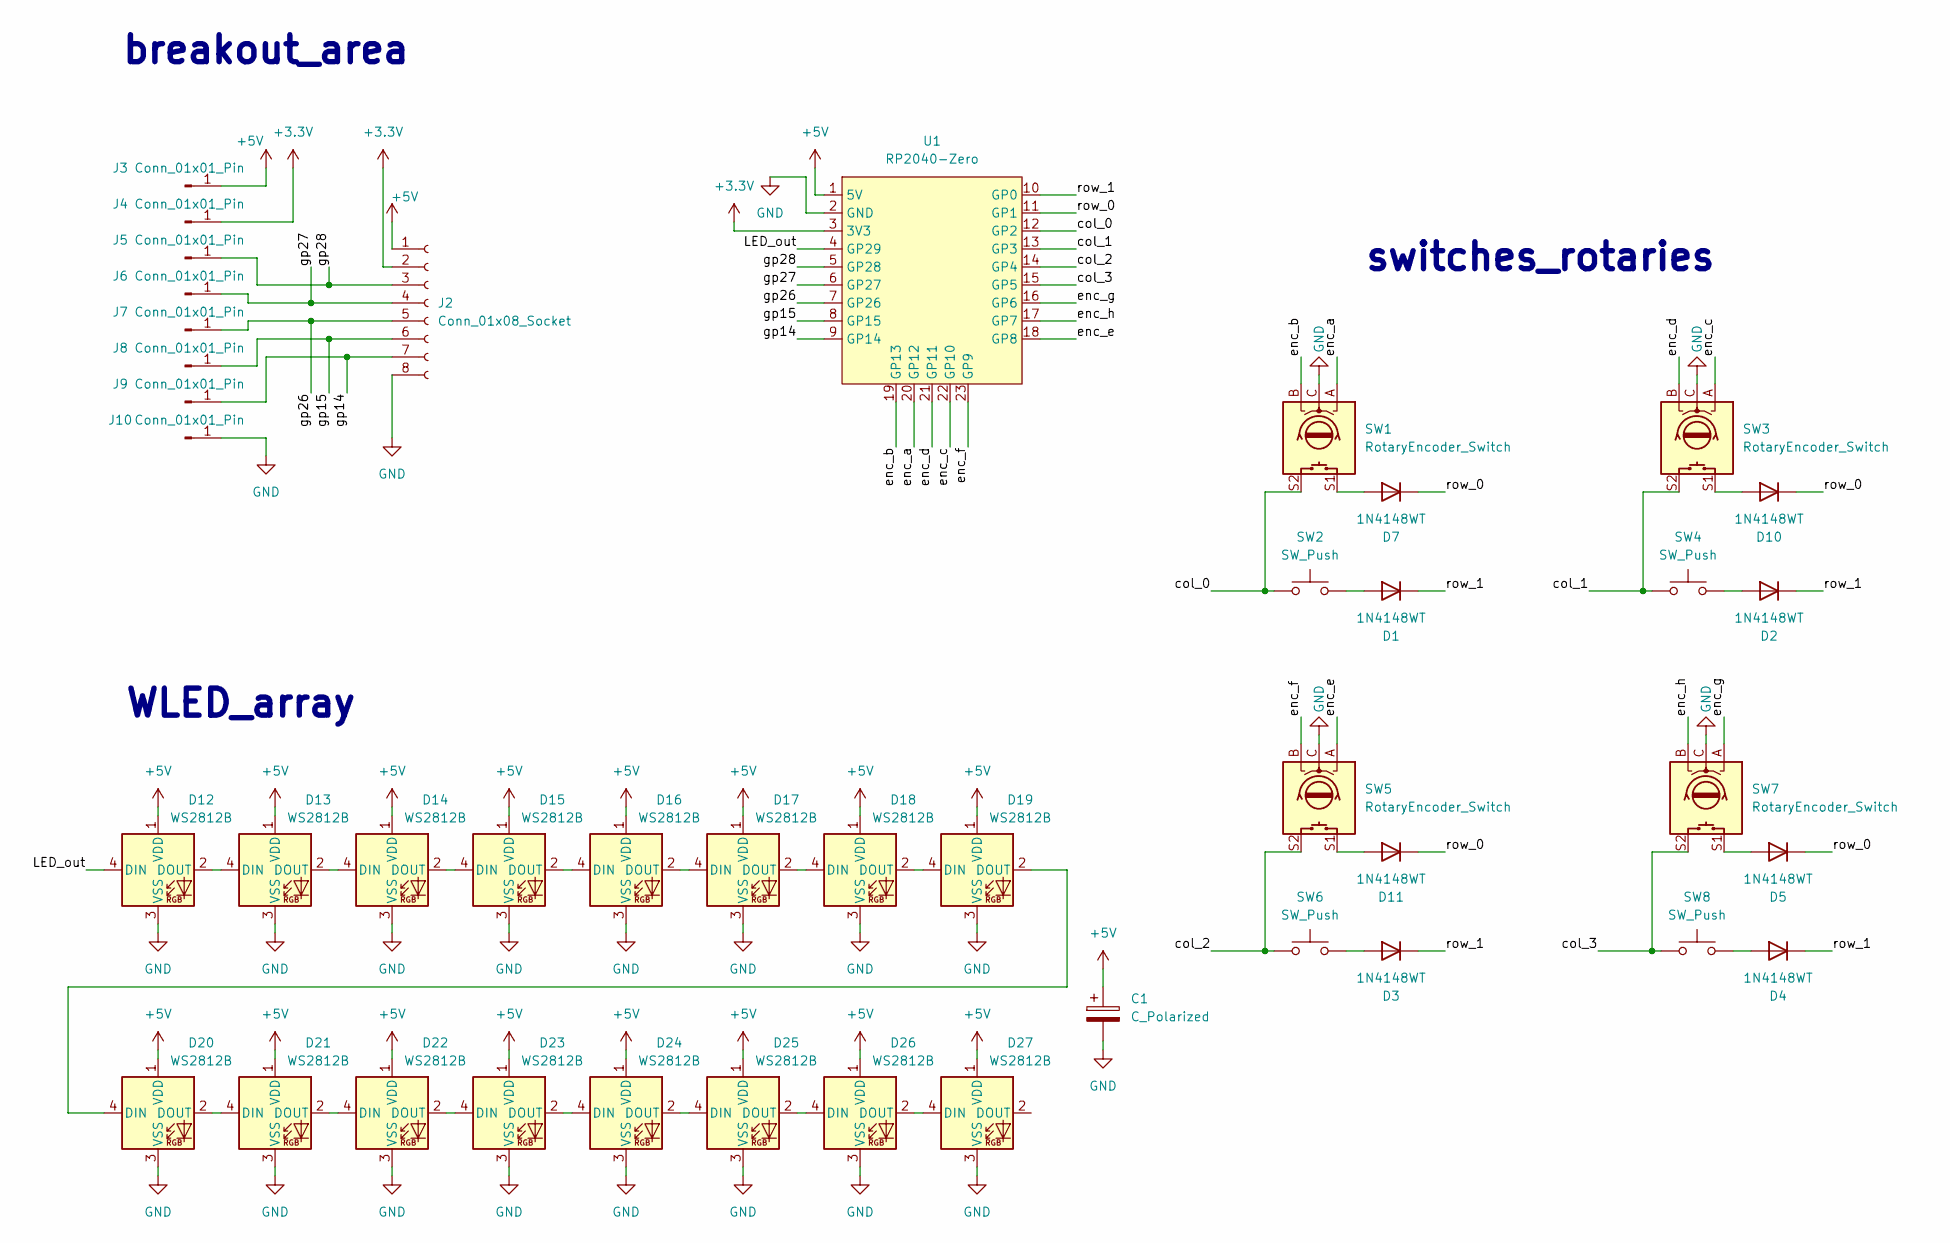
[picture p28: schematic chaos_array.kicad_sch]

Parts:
C1: C_Polarized; CP_Elec_6.3x5.8
D1, D2, D3, D4, D5, D7, D10, D11: 1N4148WT; D_MiniMELF
D12, D13, D14, D15, D16, D17, D18, D19, D20, D21, D22, D23, D24, D25, D26, D27: WS2812B; LED_WS2812B_PLCC4_5.0x5.0mm_P3.2mm
J2: Conn_01x08_Socket; JST_EH_B8B-EH-A_1x08_P2.50mm_Vertical
J3, J4, J5, J6, J7, J8, J9, J10: Conn_01x01_Pin; TestPoint_Pad_3.0x3.0mm
SW1, SW3, SW5, SW7: RotaryEncoder_Switch; Kailh_socket_MX_PG1350_EC11_optional
SW2, SW4, SW6, SW8: SW_Push; Kailh_socket_MX_PG1350_optional
U1: RP2040-Zero; RP2040 Zero

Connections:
+3.3V: J2.2, J4.1 (Pin_1_1), U1.3 (3V3)
+5V: C1.1, D12.1 (VDD), D13.1 (VDD), D14.1 (VDD), D15.1 (VDD), D16.1 (VDD), D17.1 (VDD), D18.1 (VDD), D19.1 (VDD), D20.1 (VDD), D21.1 (VDD), D22.1 (VDD), D23.1 (VDD), D24.1 (VDD), D25.1 (VDD), D26.1 (VDD), D27.1 (VDD), J2.1, J3.1 (Pin_1_1), U1.1 (5V)
/LED_out: D12.4 (DIN), U1.4 (GP29)
/col_0: SW1.S2, SW2.1, U1.12 (GP2)
/col_1: SW3.S2, SW4.1, U1.13 (GP3)
/col_2: SW5.S2, SW6.1, U1.14 (GP4)
/col_3: SW7.S2, SW8.1, U1.15 (GP5)
/enc_a: SW1.A, U1.20 (GP12)
/enc_b: SW1.B, U1.19 (GP13)
/enc_c: SW3.A, U1.22 (GP10)
/enc_d: SW3.B, U1.21 (GP11)
/enc_e: SW5.A, U1.18 (GP8)
/enc_f: SW5.B, U1.23 (GP9)
/enc_g: SW7.A, U1.16 (GP6)
/enc_h: SW7.B, U1.17 (GP7)
/gp14: J2.7, J9.1 (Pin_1_1), U1.9 (GP14)
/gp15: J2.6, J8.1 (Pin_1_1), U1.8 (GP15)
/gp26: J2.5, J7.1 (Pin_1_1), U1.7 (GP26)
/gp27: J2.4, J6.1 (Pin_1_1), U1.6 (GP27)
/gp28: J2.3, J5.1 (Pin_1_1), U1.5 (GP28)
/row_0: D5.1 (K), D7.1 (K), D10.1 (K), D11.1 (K), U1.11 (GP1)
/row_1: D1.1 (K), D2.1 (K), D3.1 (K), D4.1 (K), U1.10 (GP0)
GND: C1.2, D12.3 (VSS), D13.3 (VSS), D14.3 (VSS), D15.3 (VSS), D16.3 (VSS), D17.3 (VSS), D18.3 (VSS), D19.3 (VSS), D20.3 (VSS), D21.3 (VSS), D22.3 (VSS), D23.3 (VSS), D24.3 (VSS), D25.3 (VSS), D26.3 (VSS), D27.3 (VSS), J2.8, J10.1 (Pin_1_1), SW1.C, SW3.C, SW5.C, SW7.C, U1.2 (GND)
unnamed: D1.2 (A), SW2.2
unnamed: D2.2 (A), SW4.2
unnamed: D3.2 (A), SW6.2
unnamed: D4.2 (A), SW8.2
unnamed: D5.2 (A), SW7.S1
unnamed: D7.2 (A), SW1.S1
unnamed: D10.2 (A), SW3.S1
unnamed: D11.2 (A), SW5.S1
unnamed: D12.2 (DOUT), D13.4 (DIN)
unnamed: D13.2 (DOUT), D14.4 (DIN)
unnamed: D14.2 (DOUT), D15.4 (DIN)
unnamed: D15.2 (DOUT), D16.4 (DIN)
unnamed: D16.2 (DOUT), D17.4 (DIN)
unnamed: D17.2 (DOUT), D18.4 (DIN)
unnamed: D18.2 (DOUT), D19.4 (DIN)
unnamed: D19.2 (DOUT), D20.4 (DIN)
unnamed: D20.2 (DOUT), D21.4 (DIN)
unnamed: D21.2 (DOUT), D22.4 (DIN)
unnamed: D22.2 (DOUT), D23.4 (DIN)
unnamed: D23.2 (DOUT), D24.4 (DIN)
unnamed: D24.2 (DOUT), D25.4 (DIN)
unnamed: D25.2 (DOUT), D26.4 (DIN)
unnamed: D26.2 (DOUT), D27.4 (DIN)

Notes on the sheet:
switches_rotaries
WLED_array
breakout_area

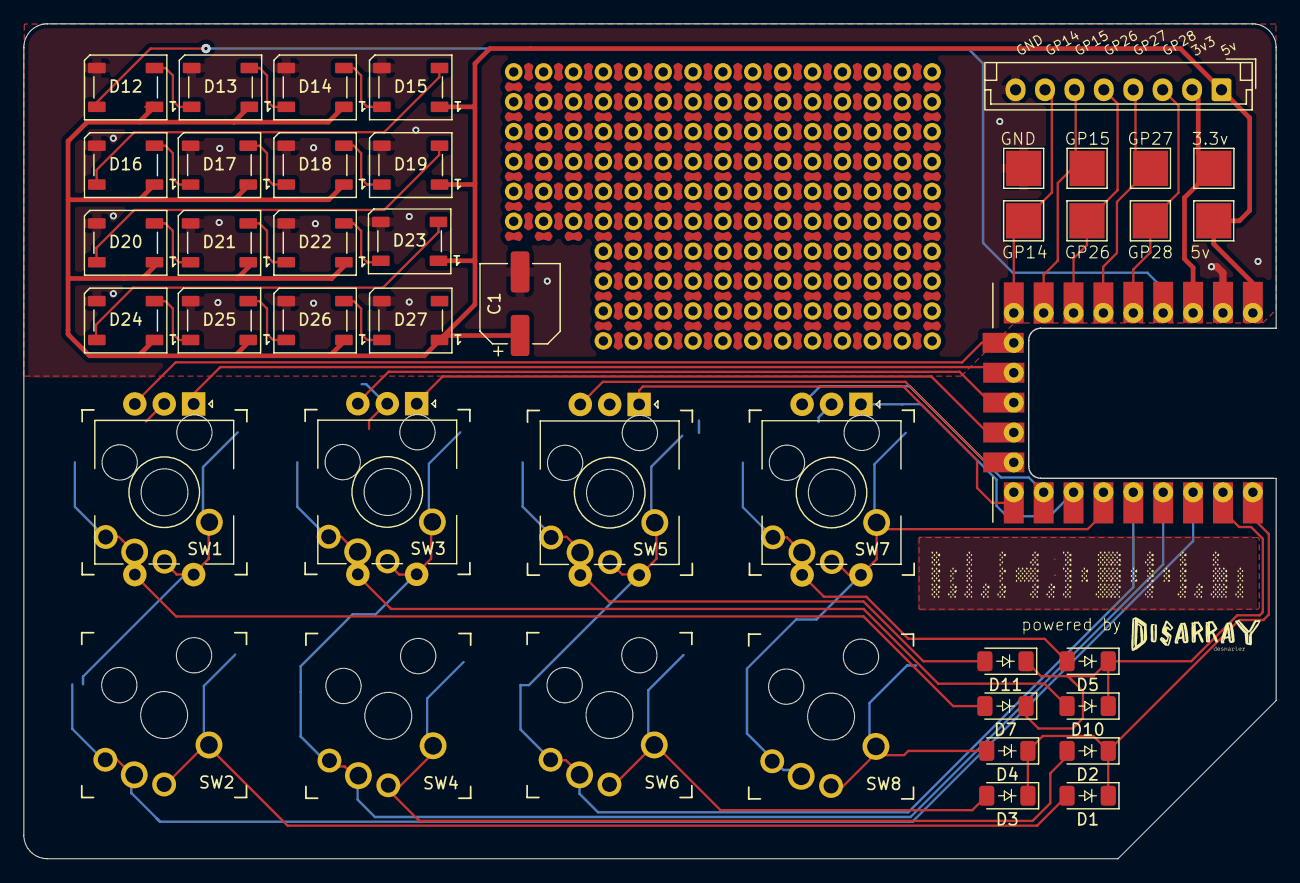
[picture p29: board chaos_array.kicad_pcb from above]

Board: 2 copper layers, 106.4 x 71.0 mm, 43 parts (0 on the bottom side), 46 nets.

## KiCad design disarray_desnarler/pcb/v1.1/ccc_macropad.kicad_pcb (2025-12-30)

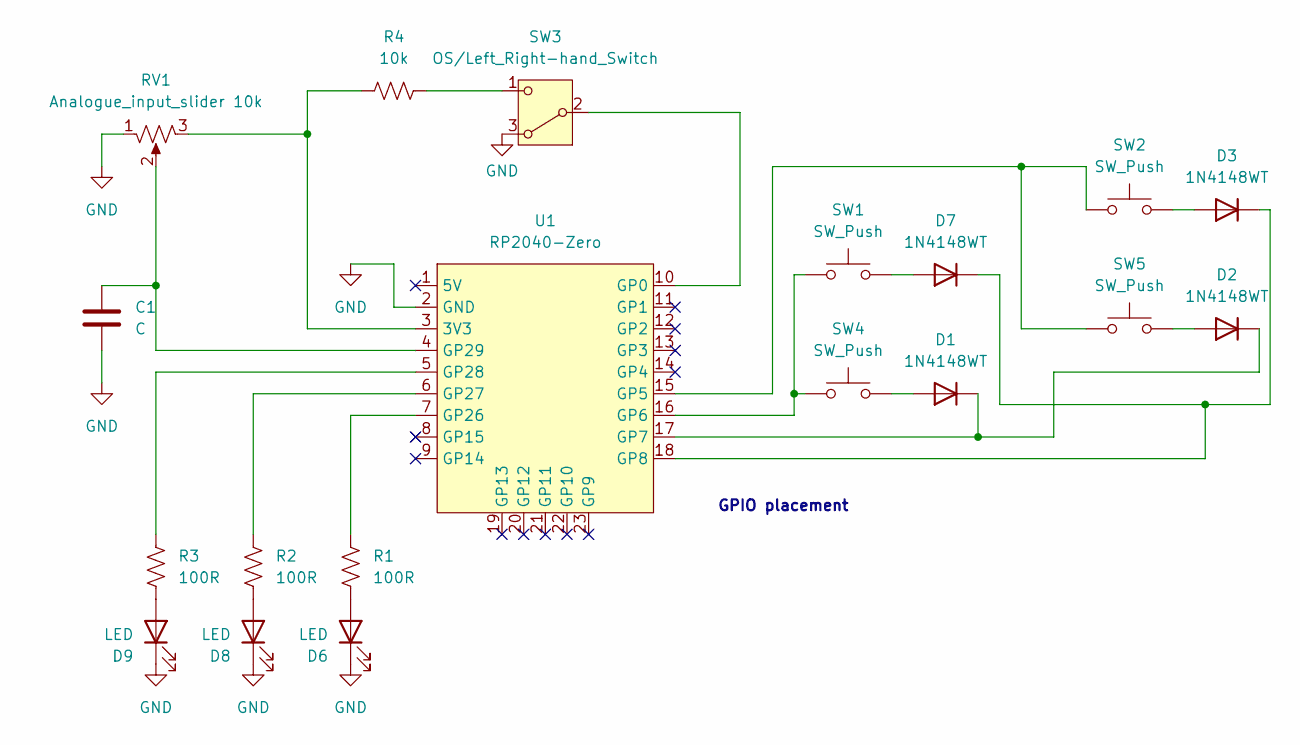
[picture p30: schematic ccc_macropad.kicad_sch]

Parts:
C1: C; C_Disc_D5.0mm_W2.5mm_P5.00mm
D1, D2, D3, D7: 1N4148WT; D_DO-35_SOD27_P5.08mm_Horizontal
D6, D8, D9: LED; LED_D3.0mm
R1, R2, R3: 100R; R_Axial_DIN0204_L3.6mm_D1.6mm_P5.08mm_Horizontal
R4: 10k; R_Axial_DIN0204_L3.6mm_D1.6mm_P5.08mm_Horizontal
RV1: Analogue_input_slider 10k; Potentiometer_slide_75mm_range_60mm_2_sets
SW1, SW2, SW4, SW5: SW_Push; Kailh_socket_MX_PG1350_optional
SW3: OS/Left_Right-hand_Switch; SPDT_3pin_2_pos_1P2T_tht_2.54mm_switch_sk12d07
U1: RP2040-Zero; RP2040 Zero

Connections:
GND: C1.2, D6.1 (K), D8.1 (K), D9.1 (K), RV1.1, SW3.3 (A), U1.2 (GND)
unnamed: D1.2 (A), SW4.2
unnamed: D1.1 (K), D2.1 (K), U1.17 (GP7)
unnamed: D2.2 (A), SW5.2
unnamed: D3.2 (A), SW2.2
unnamed: D3.1 (K), D7.1 (K), U1.18 (GP8)
unnamed: D6.2 (A), R1.1
unnamed: D7.2 (A), SW1.2
unnamed: D8.2 (A), R2.1
unnamed: D9.2 (A), R3.1
unnamed: SW3.2 (B), U1.10 (GP0)
unnamed: R4.1, SW3.1 (C)
unnamed: R4.2, RV1.3, U1.3 (3V3)
unnamed: SW2.1, SW5.1, U1.15 (GP5)
unnamed: SW1.1, SW4.1, U1.16 (GP6)
unnamed: R1.2, U1.7 (GP26)
unnamed: R2.2, U1.6 (GP27)
unnamed: R3.2, U1.5 (GP28)
unnamed: C1.1, RV1.2, U1.4 (GP29)

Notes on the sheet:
GPIO placement

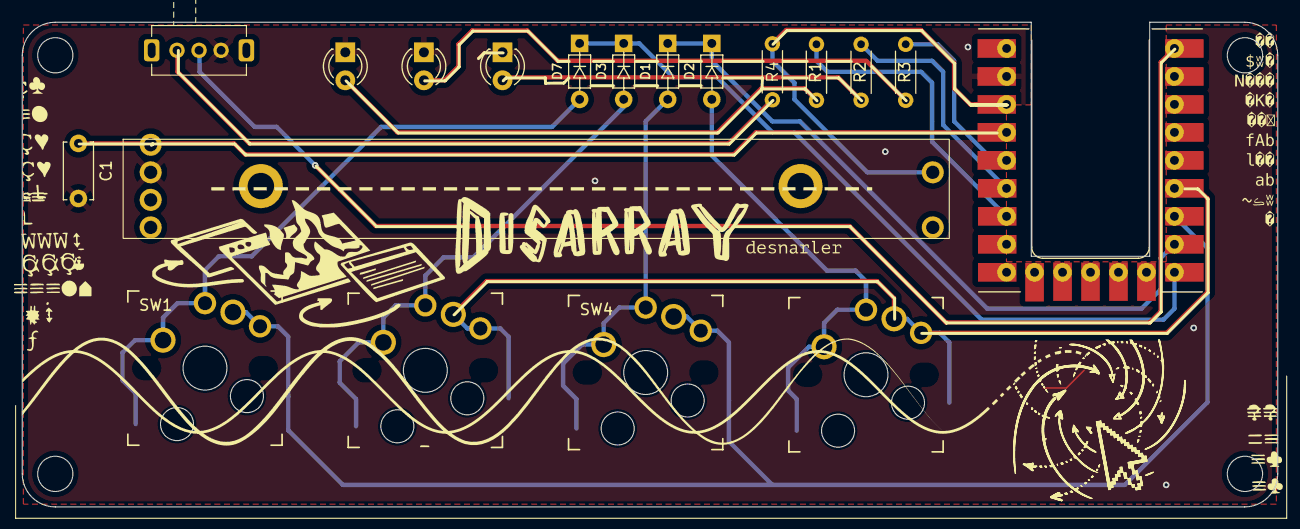
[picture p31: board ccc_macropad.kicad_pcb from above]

Board: 2 copper layers, 114.0 x 44.0 mm, 19 parts (0 on the bottom side), 19 nets.

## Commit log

2025-10-23 feat: update schematic to rp2040_zero
    [ccc_macropad.kicad_pcb, ccc_macropad.kicad_sch]
2025-10-23 PCB: feat add pinout table
    [ccc_macropad.kicad_sch]
2025-10-23 PCB: feat: new rp2040_zero footprint / rounded edges
    [ccc_macropad.kicad_pcb]
2025-10-23 PCB:chores: cleanup schematic
    [ccc_macropad.kicad_sch]
2025-10-30 feat: cutout for MCU SMD mount
    [ccc_macropad.kicad_pcb]
2025-10-30 added art to back: silkscreen and exposed copper
    [ccc_macropad.kicad_pcb]
2025-10-30 logo added to front silkscreen
    [ccc_macropad.kicad_pcb]
2025-10-31 fix: remove silkscreen of reference-switches/ reroute ground
    [ccc_macropad.kicad_pcb]
2025-10-31 fixed missing V1, added svg files to art subdirectory
    [ccc_macropad.kicad_pcb]
2025-10-31 fix: bigger traces/ more clearance
    [ccc_macropad-B_Mask.gbs, ccc_macropad-B_Paste.gbp, ccc_macropad-B_Silkscreen.gbo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]
2025-11-07 feat: add assebly guide first draft // front and back panel laser svg
    [ccc_macropad-B_Silkscreen.dxf, ccc_macropad-Edge_Cuts.dxf, ccc_macropad-F_Silkscreen.dxf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]
2025-11-11 feat: add first draft assembly instructions
2025-11-14 fix: add soldering pic
2025-11-20 feat: add buffer capacitor//increase board size// add foot holes
    [ccc_macropad.kicad_pcb, ccc_macropad.kicad_sch]
2025-11-20 refactoring: mini adjustments
    [ccc_macropad.kicad_pcb]
2025-11-21 chores: duplicate PCBs for update to v1
    [ccc_macropad-B_Mask.gbs, ccc_macropad-B_Paste.gbp, ccc_macropad-B_Silkscreen.gbo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]
2025-11-22 chores: proper versioning of art and PCBs
    [ccc_macropad-B_Silkscreen.dxf, ccc_macropad-Edge_Cuts.dxf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]
2025-11-30 removed unnecessary leftover vector layers from svg files for the laser-cut case, greatly reducing file size
2025-11-30 removed old and unnecessary svg and dxf files
    [ccc_macropad-B_Silkscreen.dxf, ccc_macropad-Edge_Cuts.dxf, ccc_macropad-F_Silkscreen.dxf]
2025-11-30 restored missing silkscreen_front.svg, sorted case files into case_design directory
2025-12-01 restored v1.1 PCB files, added new build diagram files
    [ccc_macropad.kicad_pcb]
2025-12-01 rearranged art files into /PCB/PCB_vector_art, /logo, and /lasercut_case
2025-12-04 fix: clean up
    [ccc_macropad-B_Mask.gbs, ccc_macropad-B_Paste.gbp, ccc_macropad-B_Silkscreen.gbo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]
2025-12-25 fix: insert image
2025-12-26 feat: update soldering instructions
2025-12-30 chores: create updated gerbers
    [ccc_macropad-B_Courtyard.gbr, ccc_macropad-B_Mask.gbs, ccc_macropad-B_Silkscreen.gbo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]
2025-12-30 feat: add fader knob stl-file
    [Fader_knob-Body.stl]
2026-04-22 fix(lasercut case design): add current case design, move old design files to separate directory
2026-04-24 chore(lasercut case): replace .ai files with .svg files
2026-05-05 Add Kicad_Project v2.0
    [chaos_array-B_Courtyard.gbr, chaos_array-B_Mask.gbs, chaos_array-B_Paste.gbp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]
2026-05-05 Add footprints and symbols
2026-05-06 Create LED array and breakout area
    [chaos_array.kicad_sch]
2026-05-06 update BOM
    [chaos_array.kicad_sch]
2026-05-06 Update footprints
    [RP2040_Zero.stp, chaos_array.kicad_sch]
2026-05-06 basic layout PCB
    [chaos_array.kicad_pcb]
2026-05-18 PCE reassemble switches
    [chaos_array.kicad_pcb]
2026-09-20 Add gerbers and edge cuts
    [chaos_array-B_Courtyard.dxf, chaos_array-B_Mask.dxf, chaos_array-B_Paste.dxf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]
2026-09-20 Update folder structure
    [Fader_knob-Body.stl, RP2040_Zero.stp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]
2026-09-20 fix version num
    [chaos_array-B_Courtyard.dxf, chaos_array-B_Mask.dxf, chaos_array-B_Paste.dxf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]
